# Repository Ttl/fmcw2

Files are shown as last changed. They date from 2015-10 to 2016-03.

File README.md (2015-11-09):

FMCW radar hardware, firmware and processing software.

Folders:

hardware: KiCad hardware design files.

- fmcw2: RF board.
- fmcw2_mcu: Digital board.

firmware: 
- Firmware for LPC4320 microcontroller. Based on [HackRF](https://github.com/mossmann/hackrf) firmware.

host: 
- Host programs for recording data, programming firmware. Also from HackRF with small modifications.

processing:
- fir: Resamples, filters and repackages samples for other programs.
- filter.py: Output FIR filter coefficients for fir C program.
- analysis.py: Various analyses about the recorded data.
- sar_bicycle.py: Pre-processing of raw data.
- sar_process.py: Focus raw data to SAR image.
- sar_autofocus.py: Simple minimum entropy autofocusing of SAR image.

SAR focusing program is loosely based on Matlab program by Gregory L. Charvat
and it also includes some functions from [RITSAR](https://github.com/dm6718/RITSAR).

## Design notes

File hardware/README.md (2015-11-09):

PCB info:

OSH Park 4-layer.

Material: FR408

Relative permittivity: 3.66

Tangent delta: 0.0127

Stackup:

- 1 mil solder resist
- 1 oz copper (1.4 mil)
- 6.7 mil prepreg
- 0.5 oz copper (0.7 mil)
- 47 mil core
- 0.5 oz copper (0.7 mil)
- 6.7 mil prepreg
- 1 oz copper (1.4 mil)
- 1 mil solder resist

More information: http://support.oshpark.com/support/solutions/articles/122263-4-layer-board-stackup-and-specifications

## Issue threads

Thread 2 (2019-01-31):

Bill of Materials?

zack-emmert, 2019-01-31:
I'm interested in re-creating this project, but I can't seem to find a list of all electronic components soldered to the PCBs. This information would be very helpful.

Ttl, 2019-02-01:
You can export a BOM from KiCad.

I strongly recommend building the next version of this radar in https://github.com/Ttl/fmcw3 instead of this one.

Closed 2019-02-01.

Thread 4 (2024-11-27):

can not find symbol and footprint

RaderWu, 2024-11-27:
The symbol and footprint for those KICAD schamtic and layout are missing...

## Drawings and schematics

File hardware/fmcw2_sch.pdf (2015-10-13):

# 100p BSW

100n 10V

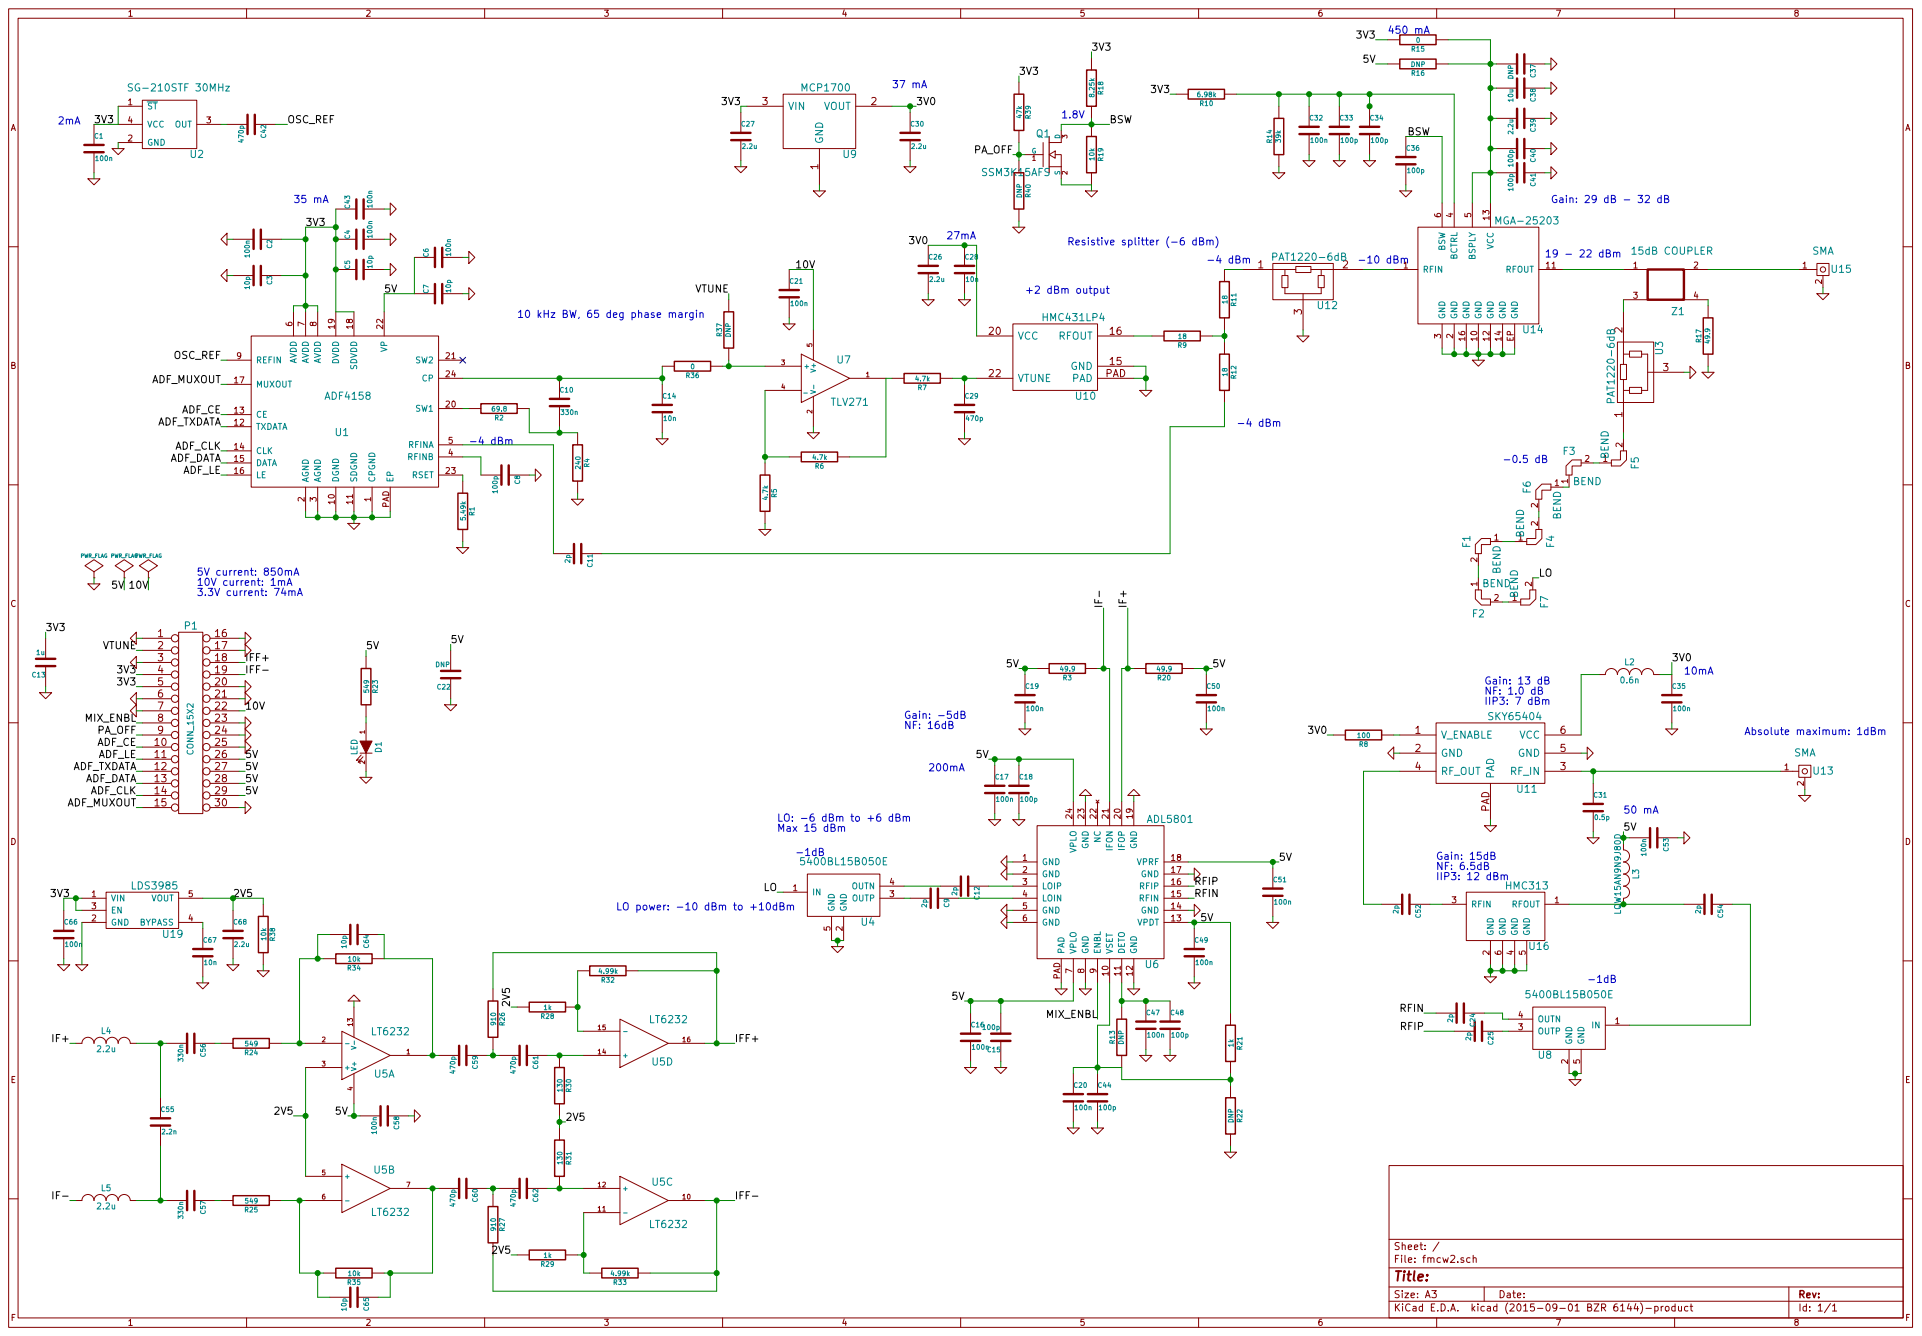
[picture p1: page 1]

6 GND 10 RFOUT 11 GND 12 VCC 13 GND 14 GND 16 GND EPU14 MGA-25203 C40 100p C39 2.2u 10u C38 DNP C37 C34

10 kHz BW, 65 deg phase margin

8 REFIN 9 DGND 10 SW1 20 SDGND 11 SW2 21 TXDATA 12 VP 22 CE 13 RSET 23 CLK 14 CP 24 DATA 15

9 VSET 10 IFOP 20 DETO 11 IFON 21 GND 12 NC 22 VPDT 13 GND 23 GND 14 VPLO 24 RFIN 15 RFIP 16 GND 17 VPRF 18 GND 19 PAD PADU6ADL5801 IF- IF+ RFIP RFIN

Id: 1/1 Title: File: fmcw2.sch Sheet: /

P0_1 G1 | P1_0 H1 | P1_3 J1 | P1_2 K1 | ADC0 A2 | VDDA B² VSSA C² USB_VDDA3V3 D2 | USB_DM E2 | USB_VSSA_REF F2
P1_4 J2 | P1_1 K2 | ADC3 A3 | ADC2 B3 | ALARM C3 | USB_VSSA_TERM D3 | USB_VBUS E3 | USB_RREF F3 | TDI G3 | TDO H3 | VSSIO J3 CLK0 K3 | WAKEUP0 A4 | TRSTN B4 | TMS C4 | VSSIO_40 D⁴ VDDREG_94 E⁴ VDDREG_59 F4 P1_7 G4

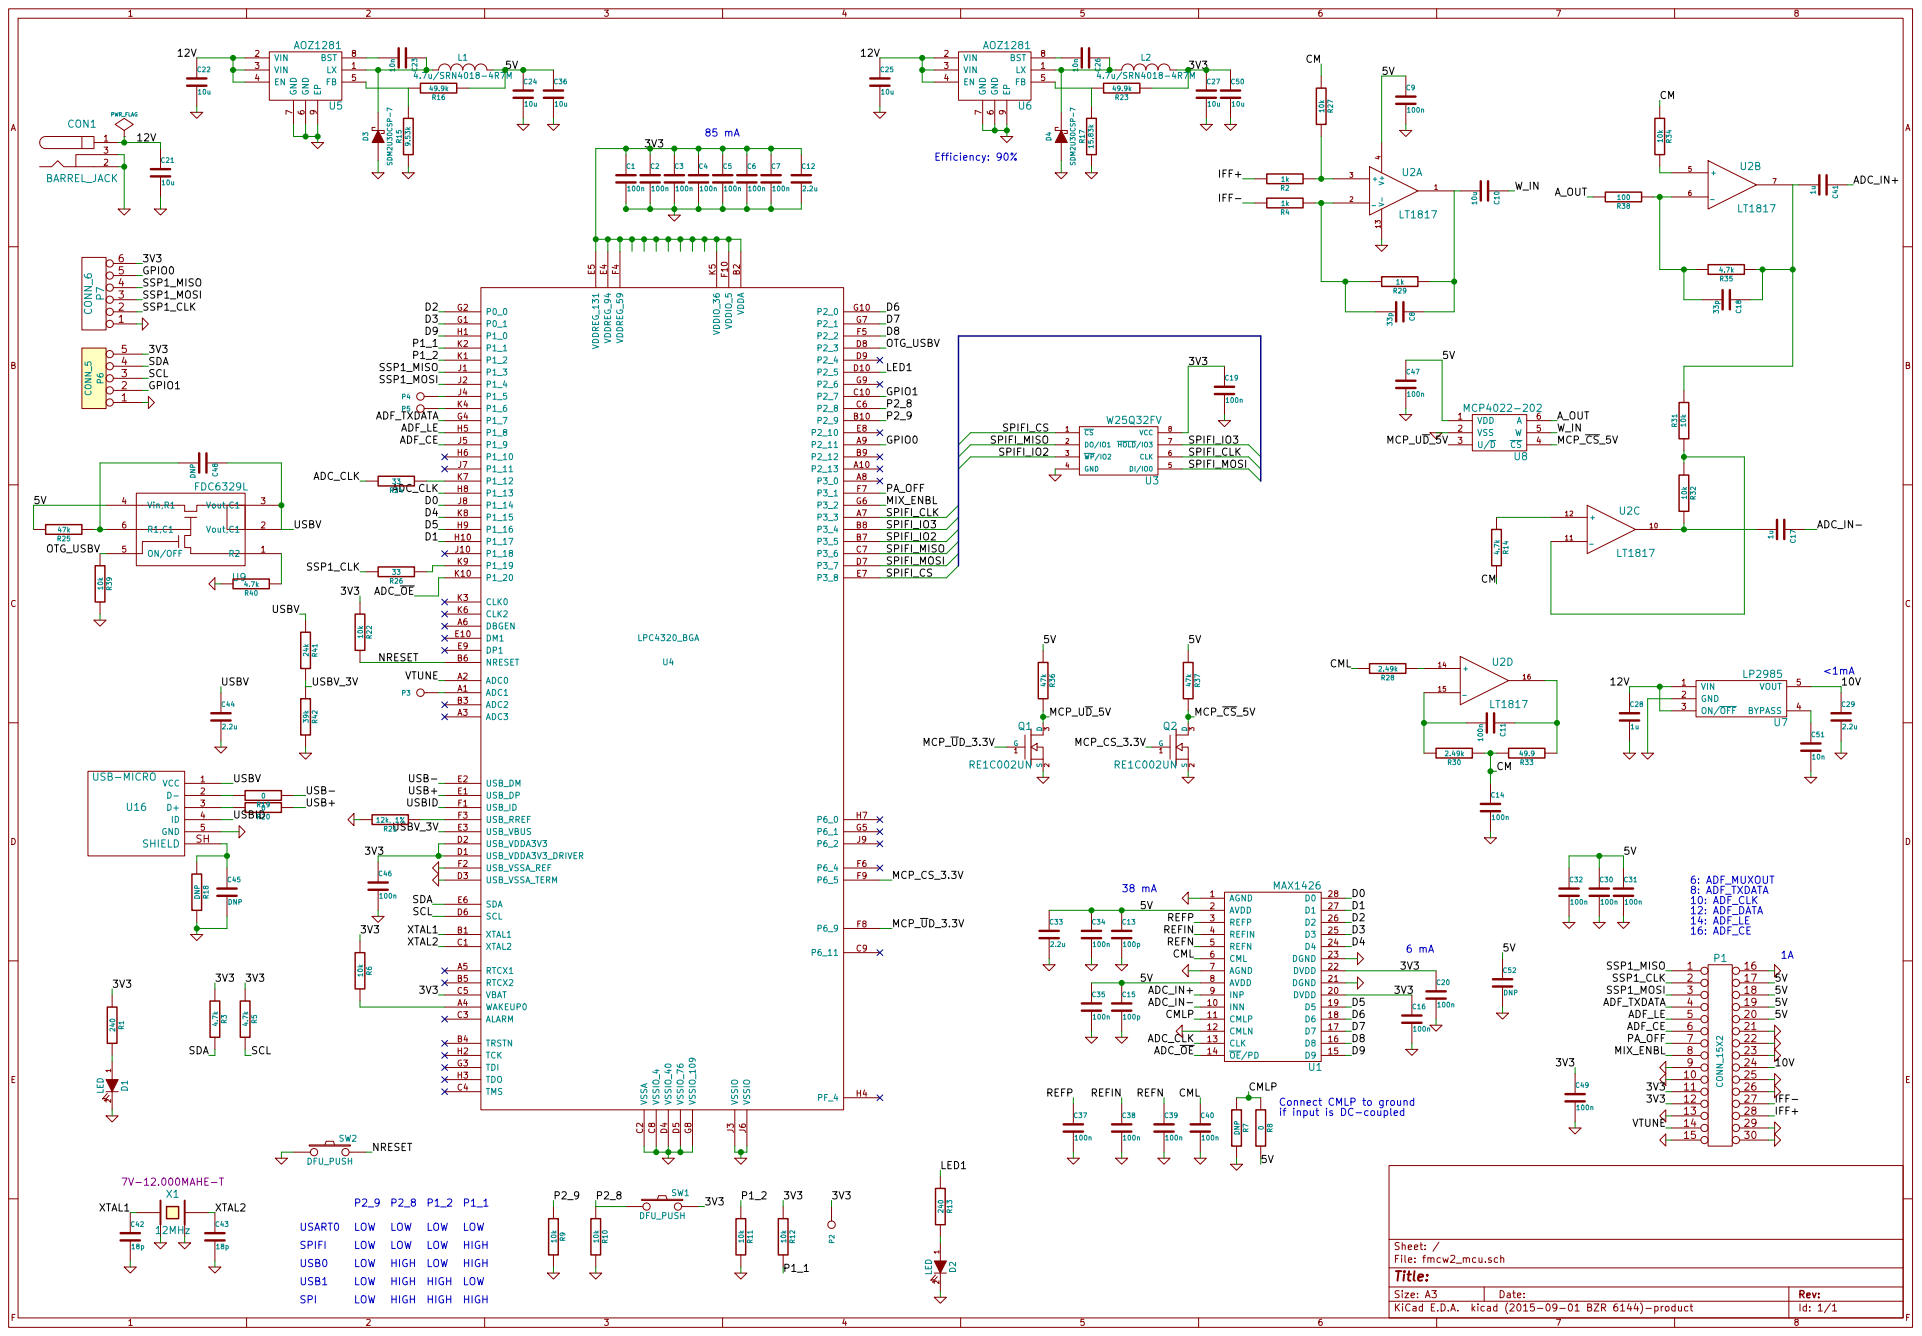
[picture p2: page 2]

VTUNE ²⁴k R⁴¹ 39k R⁴²

Connect CMLP to ground
if input is DC-coupled

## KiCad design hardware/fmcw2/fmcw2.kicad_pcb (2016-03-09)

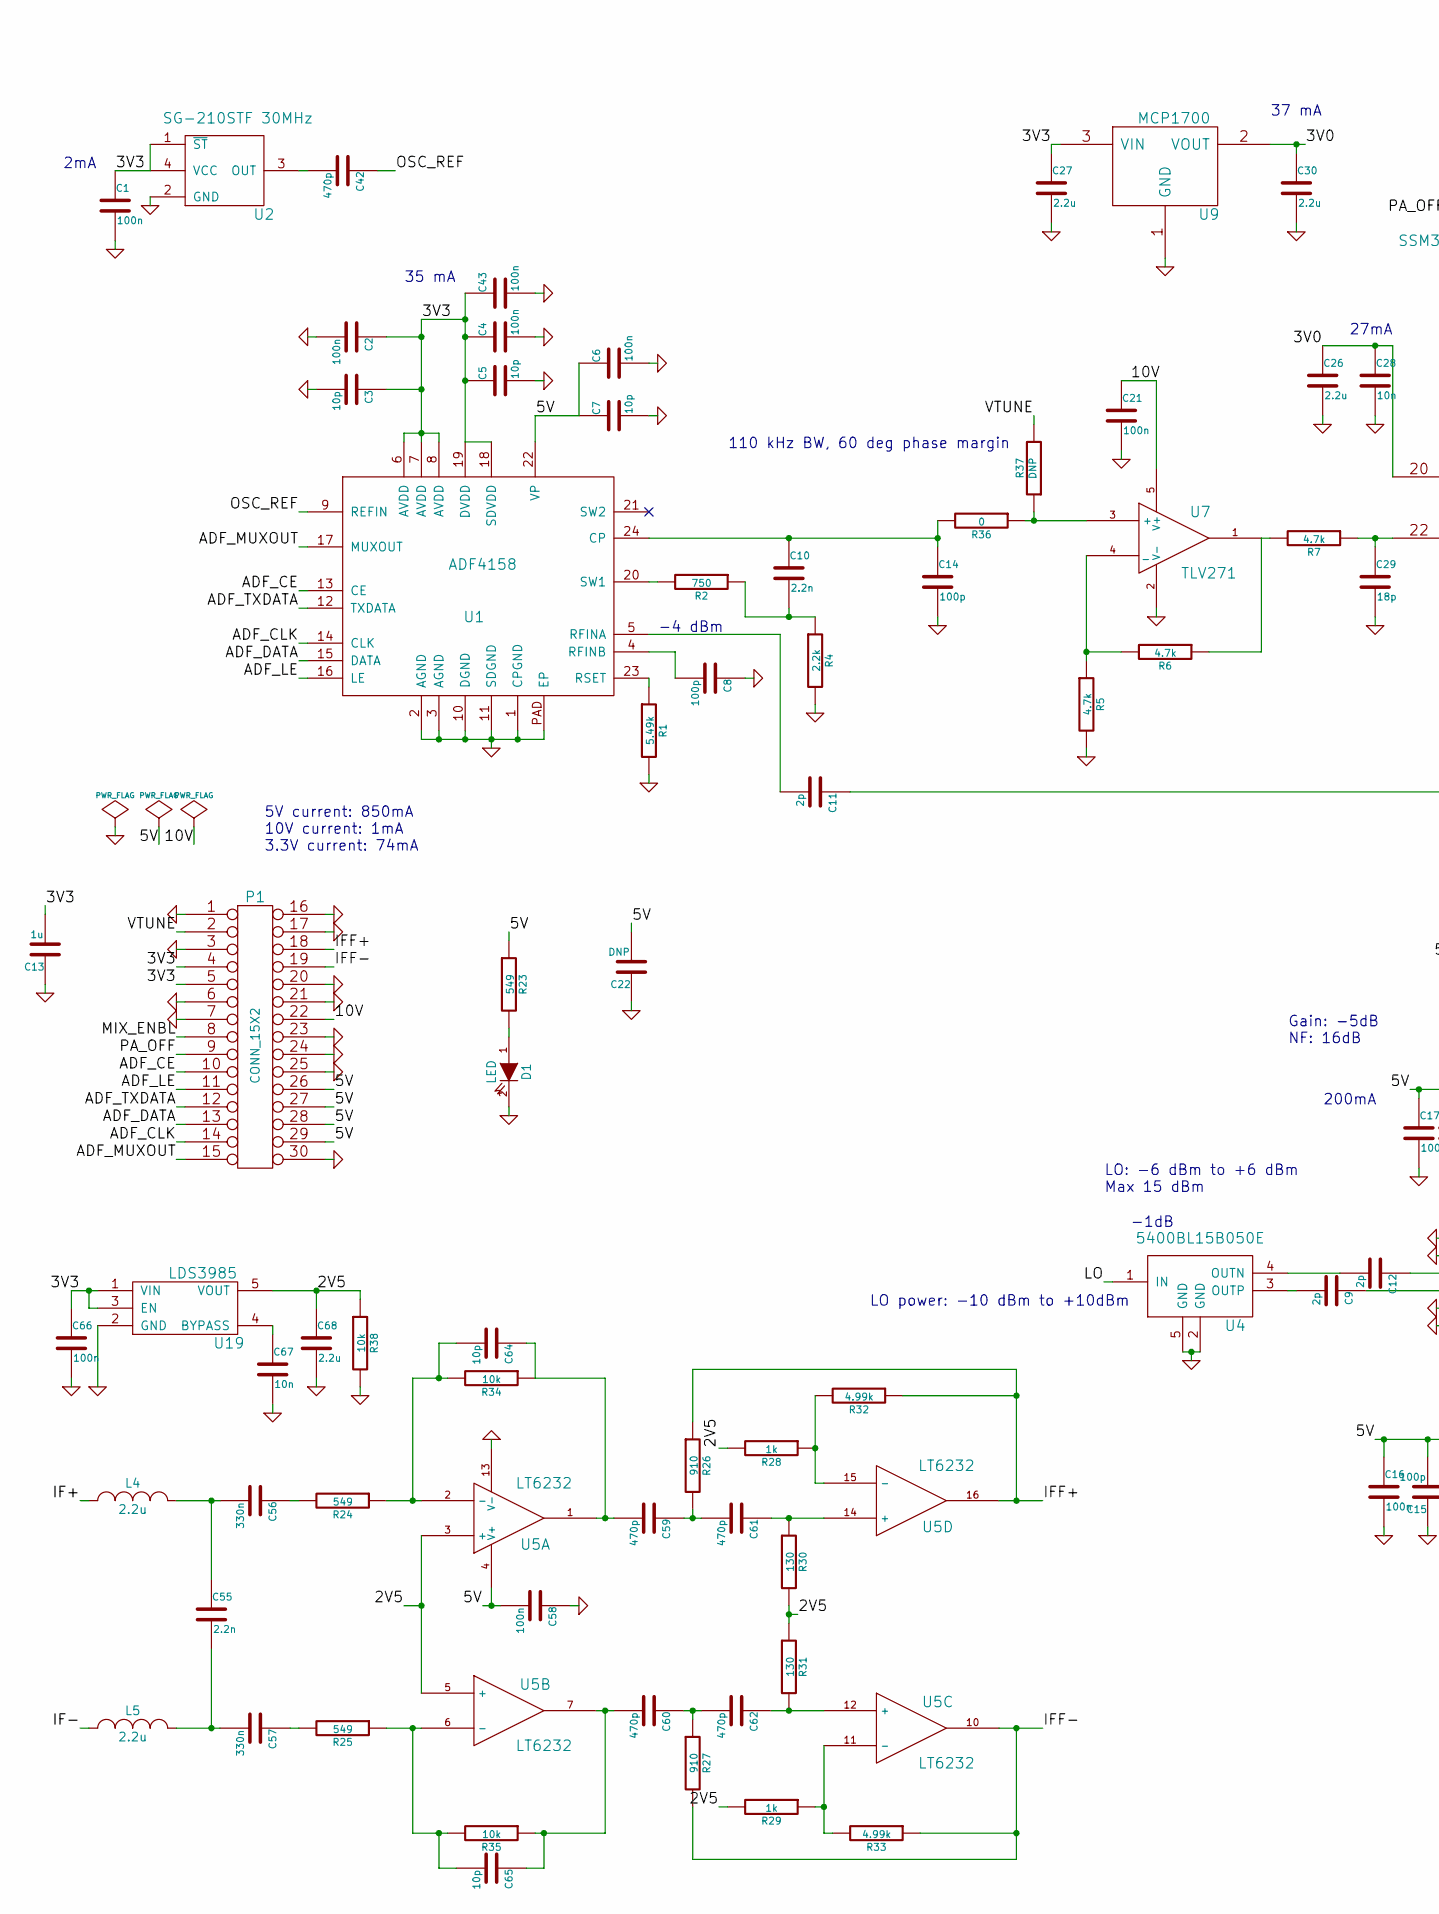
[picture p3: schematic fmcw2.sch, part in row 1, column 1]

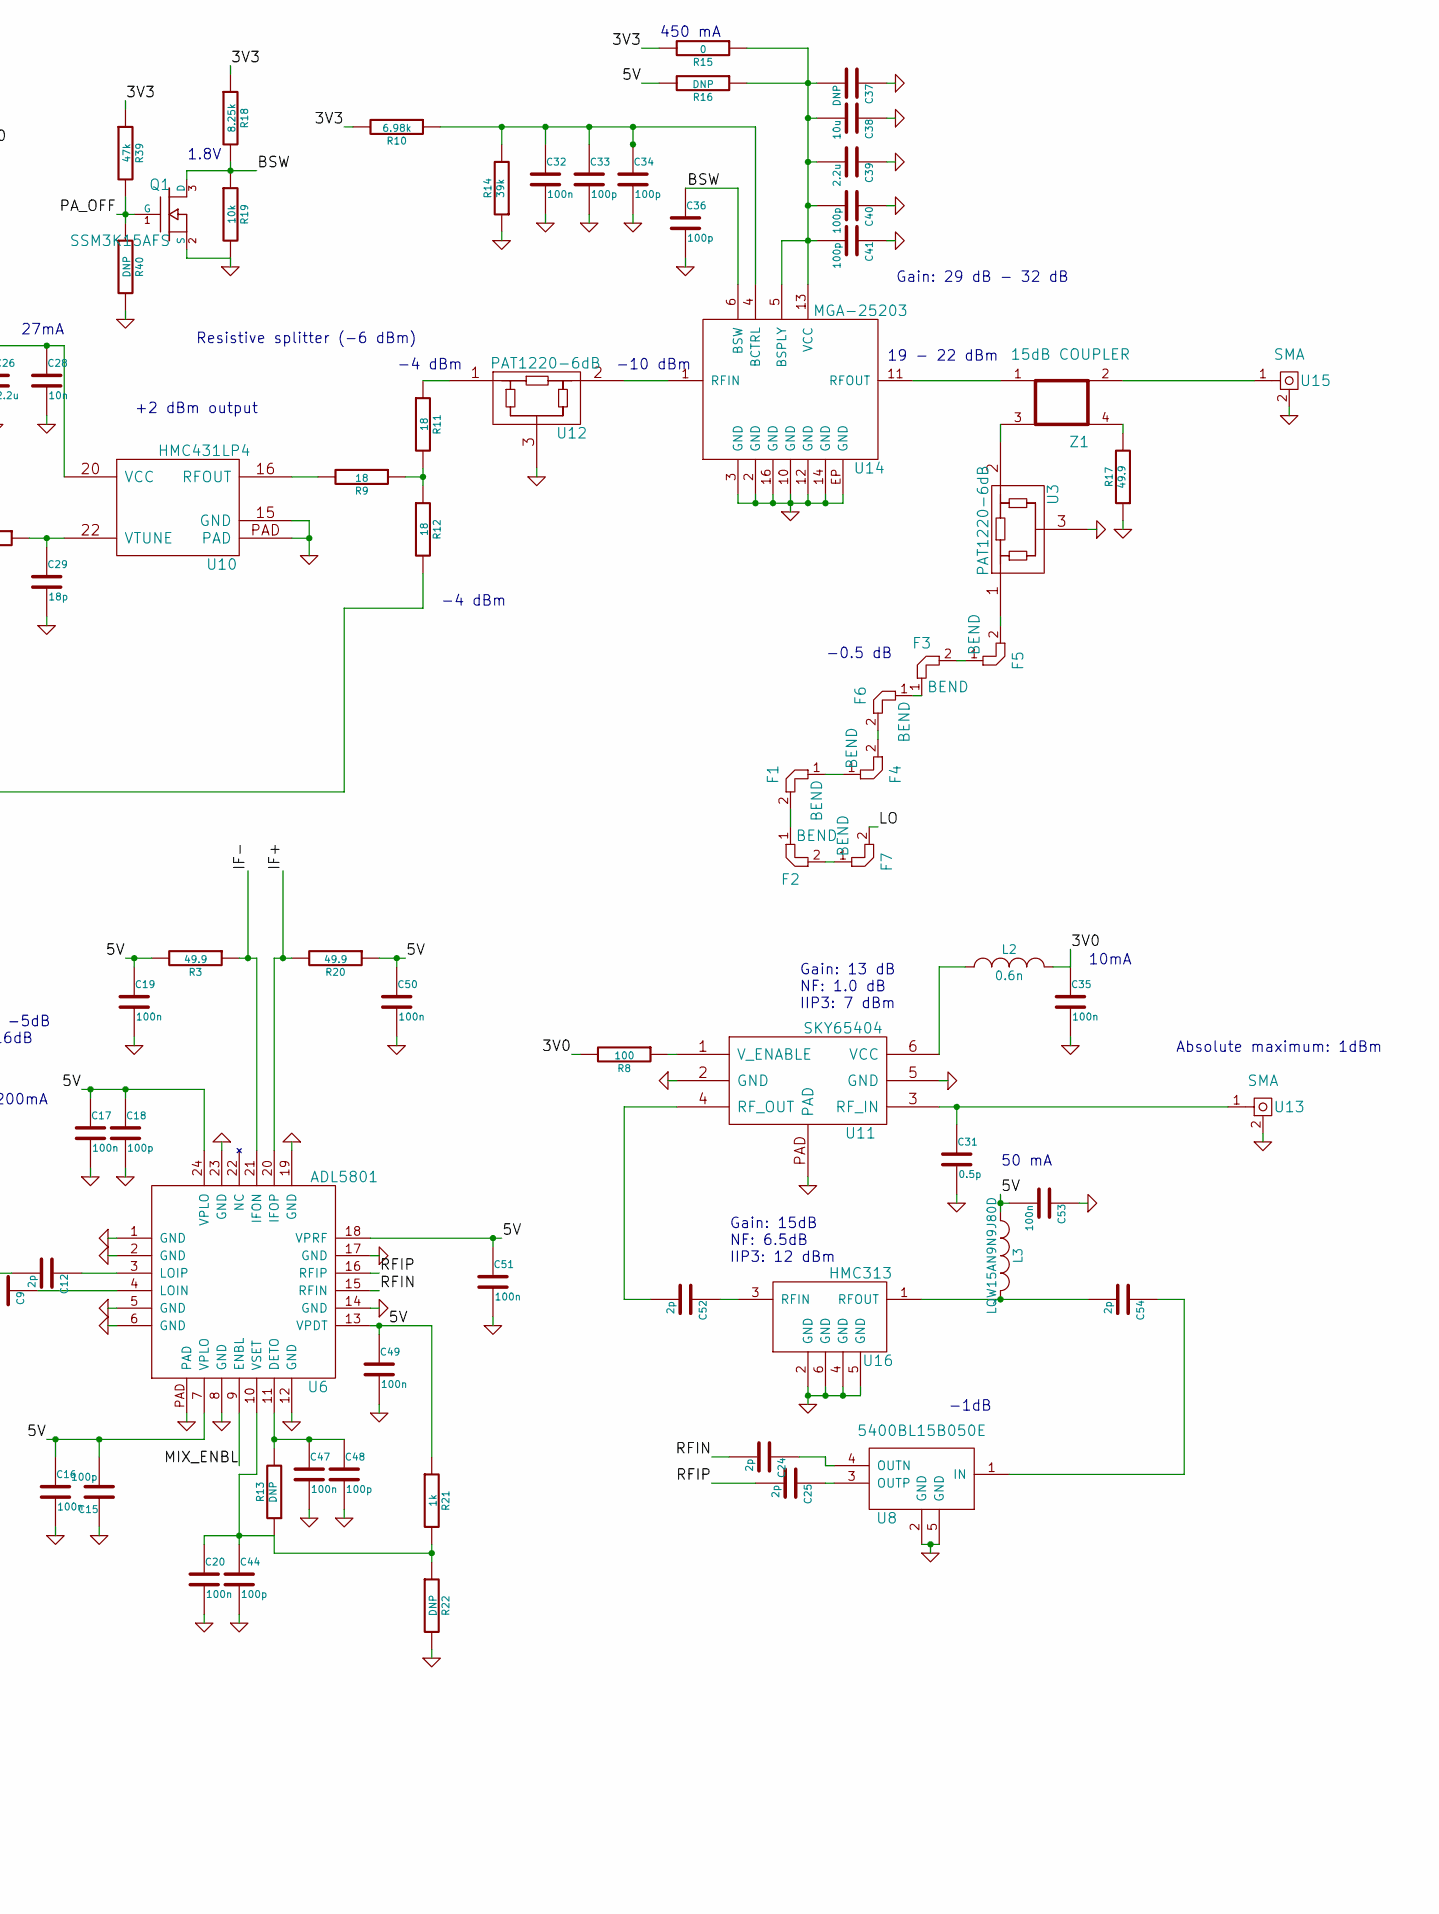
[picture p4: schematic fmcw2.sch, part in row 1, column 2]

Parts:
C1, C2, C4, C6, C16, C17, C19, C20, C21, C32, C35, C43, C47, C49, C50, C51, C53, C58, C66: 100n; C_0402b
C3, C5, C7, C64, C65: 10p; C_0402b
C8, C14, C15, C18, C33, C34, C36, C40, C41, C44, C48: 100p; C_0402b
C9, C11, C12, C24, C25, C52, C54: 2p; C_0402b
C10, C55: 2.2n; C_0402b
C13: 1u; C_0603b
C22: DNP; C_0805b
C26, C27, C30, C39, C68: 2.2u; C_0603b
C28, C67: 10n; C_0402b
C29: 18p; C_0402b
C31: 0.5p; C_0402b
C37: DNP; C_0603b
C38: 10u; C_0805b
C42, C59, C60, C61, C62: 470p; C_0402b
C56, C57: 330n; C_0603b
D1: LED; LED_0603
F1, F2, F7: BEND; uwmiter_0.34_0.17_90
F3, F4, F5, F6: BEND; uwmiter_0.34_0.17_45
L2: 0.6n; C_0402
L3: LQW15AN9N9J80D; C_0402
L4, L5: 2.2u; C_0402
P1: CONN_15X2; DF12B(5.0)-30DP-0.5V(86)
Q1: SSM3K15AFS; SOT-416
R1: 5.49k; R_0402b
R2: 750; R_0402b
R3, R17, R20: 49.9; R_0402b
R4: 2.2k; R_0402b
R5, R6, R7: 4.7k; R_0402b
R8: 100; R_0402b
R9, R11, R12: 18; R_0402b
R10: 6.98k; R_0402b
R13, R16, R22, R37, R40: DNP; R_0402b
R14: 39k; R_0402b
R15, R36: 0; R_0402b
R18: 8.25k; R_0402b
R19, R34, R35, R38: 10k; R_0402b
R21, R28, R29: 1k; R_0402b
R23, R24, R25: 549; R_0402b
R26, R27: 910; R_0402b
R30, R31: 130; R_0402b
R32, R33: 4.99k; R_0402b
R39: 47k; R_0402b
U1: ADF4158; VFQFN-24
U2: SG-210STF 30MHz; SG-210STF
U3, U12: PAT1220-6dB; PAT1220
U4, U8: 5400BL15B050E
U5: LT6232; SSOP-16_3.9x4.9mm_Pitch0.635mm
U6: ADL5801; VFQFN-24
U7: TLV271; SOT-23-5
U9: MCP1700; SOT-23
U10: HMC431LP4; VQFN-24
U11: SKY65404; XFDFN-6
U13, U15: SMA; CONSMA003.062
U14: MGA-25203
U16: HMC313; SOT-23-6
U19: LDS3985; SOT-23-5L
Z1: 15dB COUPLER; coupler

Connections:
/2V5: C68.1, R28.2, R29.2, R30.2, R31.1, R38.1, U5.3 (+), U5.5 (+), U19.5 (VOUT)
/3V0: C26.1, C28.1, C30.1, C35.1, L2.2, R8.2, U9.2 (VOUT), U10.20 (VCC)
/3V3: C1.1, C2.1, C3.1, C4.1, C5.1, C13.2, C27.1, C43.1, C66.1, P1.4, P1.5, R10.2, R15.2, R18.1, R39.1, U1.6 (AVDD), U1.7 (AVDD), U1.8 (AVDD), U1.18 (SDVDD), U1.19 (DVDD), U2.1 (~ST), U2.4 (VCC), U9.3 (VIN), U19.1 (VIN), U19.3 (EN)
/5V: C6.1, C7.1, C15.2, C16.1, C17.1, C18.1, C19.1, C22.2, C49.1, C50.1, C51.1, C53.2, C58.2, L3.1, P1.26, P1.27, P1.28, P1.29, R3.2, R16.2, R20.1, R21.1, R23.1, U1.22 (VP), U5.4 (V+), U6.7 (VPLO), U6.13 (VPDT), U6.18 (VPRF), U6.24 (VPLO)
/10V: C21.1, P1.22, U7.5 (V+)
/ADF_CE: P1.10, U1.13 (CE)
/ADF_CLK: P1.14, U1.14 (CLK)
/ADF_DATA: P1.13, U1.15 (DATA)
/ADF_LE: P1.11, U1.16 (LE)
/ADF_MUXOUT: P1.15, U1.17 (MUXOUT)
/ADF_TXDATA: P1.12, U1.12 (TXDATA)
/BSW: C36.1, Q1.3 (D), R18.2, R19.1, U14.6 (BSW)
/IF+: L4.1, R20.2, U6.20 (IFOP)
/IF-: L5.1, R3.1, U6.21 (IFON)
/IFF+: P1.18, R26.1, R32.1, U5.16
/IFF-: P1.19, R27.2, R33.1, U5.10
/LO: F7.2, U4.1 (IN)
/MIX_ENBL: P1.8, U6.9 (ENBL)
/OSC_REF: C42.1, U1.9 (REFIN)
/PA_OFF: P1.9, Q1.1 (G), R39.2, R40.1
/RFIN: C24.2, U6.15 (RFIN)
/RFIP: C25.2, U6.16 (RFIP)
/VTUNE: P1.2, R37.2
GND: C1.2, C2.2, C3.2, C4.2, C5.2, C6.2, C7.2, C8.1, C13.1, C14.2, C15.1, C16.2, C17.2, C18.2, C19.2, C20.2, C21.2, C22.1, C26.2, C27.2, C28.2, C29.2, C30.2, C31.2, C32.2, C33.2, C34.2, C35.2, C36.2, C37.1, C38.1, C39.1, C40.1, C41.1, C43.2, C44.2, C47.2, C48.2, C49.2, C50.2, C51.2, C53.1, C58.1, C66.2, C67.2, C68.2, D1.2 (K), P1.1, P1.3, P1.6, P1.7, P1.16, P1.17, P1.20, P1.21, P1.23, P1.24, P1.25, P1.30, Q1.2 (S), R1.2, R4.2, R5.2, R14.1, R17.1, R19.2, R22.2, R38.2, R40.2, U1.1 (CPGND), U1.2 (AGND), U1.3 (AGND), U1.10 (DGND), U1.11 (SDGND), U1.PAD (EP), U2.2 (GND), U3.3, U4.2 (GND), U4.5 (GND), U5.13 (V-), U6.1 (GND), U6.2 (GND), U6.5 (GND), U6.6 (GND), U6.8 (GND), U6.12 (GND), U6.14 (GND), U6.17 (GND), U6.19 (GND), U6.23 (GND), U6.PAD, U7.2 (V-), U8.2 (GND), U8.5 (GND), U9.1 (GND), U10.15 (GND), U10.PAD, U11.2 (GND), U11.5 (GND), U11.PAD, U12.3, U13.2, U14.2 (GND), U14.3 (GND), U14.10 (GND), U14.12 (GND), U14.14 (GND), U14.16 (GND), U14.EP (GND), U15.2, U16.2 (GND), U16.4 (GND), U16.5 (GND), U16.6 (GND), U19.2 (GND)
unnamed: C8.2, U1.4 (RFINB)
unnamed: C9.1, U6.4 (LOIN)
unnamed: C9.2, U4.3 (OUTP)
unnamed: C10.1, C14.1, R36.2, U1.24 (CP)
unnamed: C10.2, R2.1, R4.1
unnamed: C11.1, R12.2
unnamed: C11.2, U1.5 (RFINA)
unnamed: C12.1, U6.3 (LOIP)
unnamed: C12.2, U4.4 (OUTN)
unnamed: C20.1, C44.1, R13.1, R21.2, R22.1, U6.10 (VSET)
unnamed: C24.1, U8.4 (OUTN)
unnamed: C25.1, U8.3 (OUTP)
unnamed: C29.1, R7.1, U10.22 (VTUNE)
unnamed: C31.1, U11.3 (RF_IN), U13.1
unnamed: C32.1, C33.1, C34.1, R10.1, R14.2, U14.4 (BCTRL)
unnamed: C37.2, C38.2, C39.2, C40.2, C41.2, R15.1, R16.1, U14.5 (BSPLY), U14.13 (VCC)
unnamed: C42.2, U2.3 (OUT)
unnamed: C47.1, C48.1, R13.2, U6.11 (DETO)
unnamed: C52.1, U16.3 (RFIN)
unnamed: C52.2, U11.4 (RF_OUT)
unnamed: C54.1, U8.1 (IN)
unnamed: C54.2, L3.2, U16.1 (RFOUT)
unnamed: C55.1, C56.2, L4.2
unnamed: C55.2, C57.2, L5.2
unnamed: C56.1, R24.2
unnamed: C57.1, R25.2
unnamed: C59.1, C61.2, R26.2
unnamed: C59.2, C64.1, R34.1, U5.1
unnamed: C60.1, C62.2, R27.1
unnamed: C60.2, C65.1, R35.1, U5.7
unnamed: C61.1, R30.1, U5.14 (+)
unnamed: C62.1, R31.2, U5.12 (+)
unnamed: C64.2, R24.1, R34.2, U5.2 (-)
unnamed: C65.2, R25.1, R35.2, U5.6 (-)
unnamed: C67.1, U19.4 (BYPASS)
unnamed: D1.1 (A), R23.2
unnamed: F1.1, F4.1
unnamed: F1.2, F2.1
unnamed: F2.2, F7.1
unnamed: F3.1, F6.1
unnamed: F3.2, F5.1
unnamed: F4.2, F6.2
unnamed: F5.2, U3.1
unnamed: L2.1, U11.6 (VCC)
unnamed: R1.1, U1.23 (RSET)
unnamed: R2.2, U1.20 (SW1)
unnamed: R5.1, R6.2, U7.4 (_)
unnamed: R6.1, R7.2, U7.1
unnamed: R8.1, U11.1 (V_ENABLE)
unnamed: R9.2, U10.16 (RFOUT)
unnamed: R11.1, U12.1
unnamed: R9.1, R11.2, R12.1
unnamed: R17.2, Z1.4
unnamed: R28.1, R32.2, U5.15 (-)
unnamed: R29.1, R33.2, U5.11 (-)
unnamed: R36.1, R37.1, U7.3 (+)
unnamed: U3.2, Z1.3
unnamed: U12.2, U14.1 (RFIN)
unnamed: U14.11 (RFOUT), Z1.1
unnamed: U15.1, Z1.2

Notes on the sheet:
Resistive splitter (-6 dBm)
+2 dBm output
-4 dBm
27mA
-10 dBm
Gain: 29 dB - 32 dB
19 - 22 dBm
110 kHz BW, 60 deg phase margin
2mA
LO: -6 dBm to +6 dBm Max 15 dBm
35 mA
450 mA
10mA
37 mA
-1dB
1.8V
Gain: 13 dB NF: 1.0 dB IIP3: 7 dBm
Gain: -5dB NF: 16dB
200mA
LO power: -10 dBm to +10dBm
Gain: 15dB NF: 6.5dB IIP3: 12 dBm
50 mA
Absolute maximum: 1dBm
5V current: 850mA 10V current: 1mA 3.3V current: 74mA
-0.5 dB

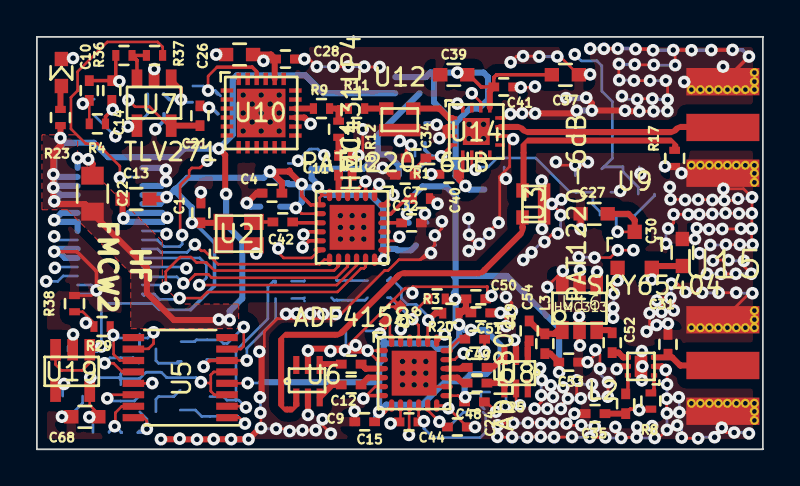
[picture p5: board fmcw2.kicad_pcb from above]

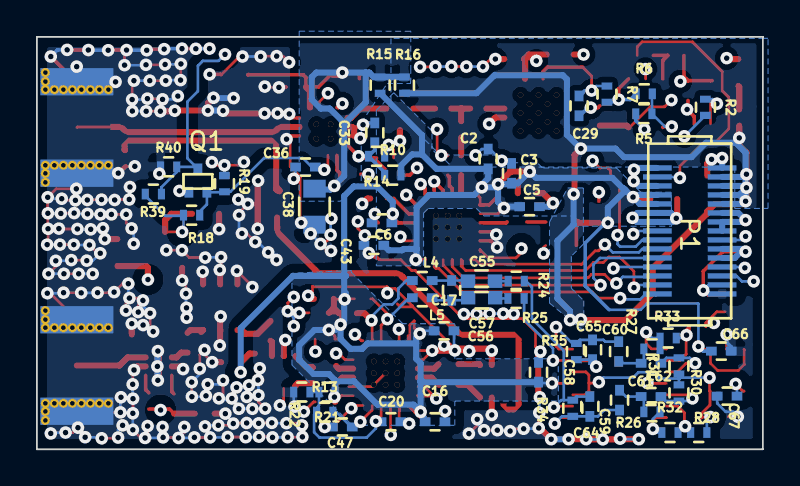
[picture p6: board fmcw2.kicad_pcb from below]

Board: 4 copper layers, 40.3 x 22.9 mm, 136 parts (55 on the bottom side), 84 nets.

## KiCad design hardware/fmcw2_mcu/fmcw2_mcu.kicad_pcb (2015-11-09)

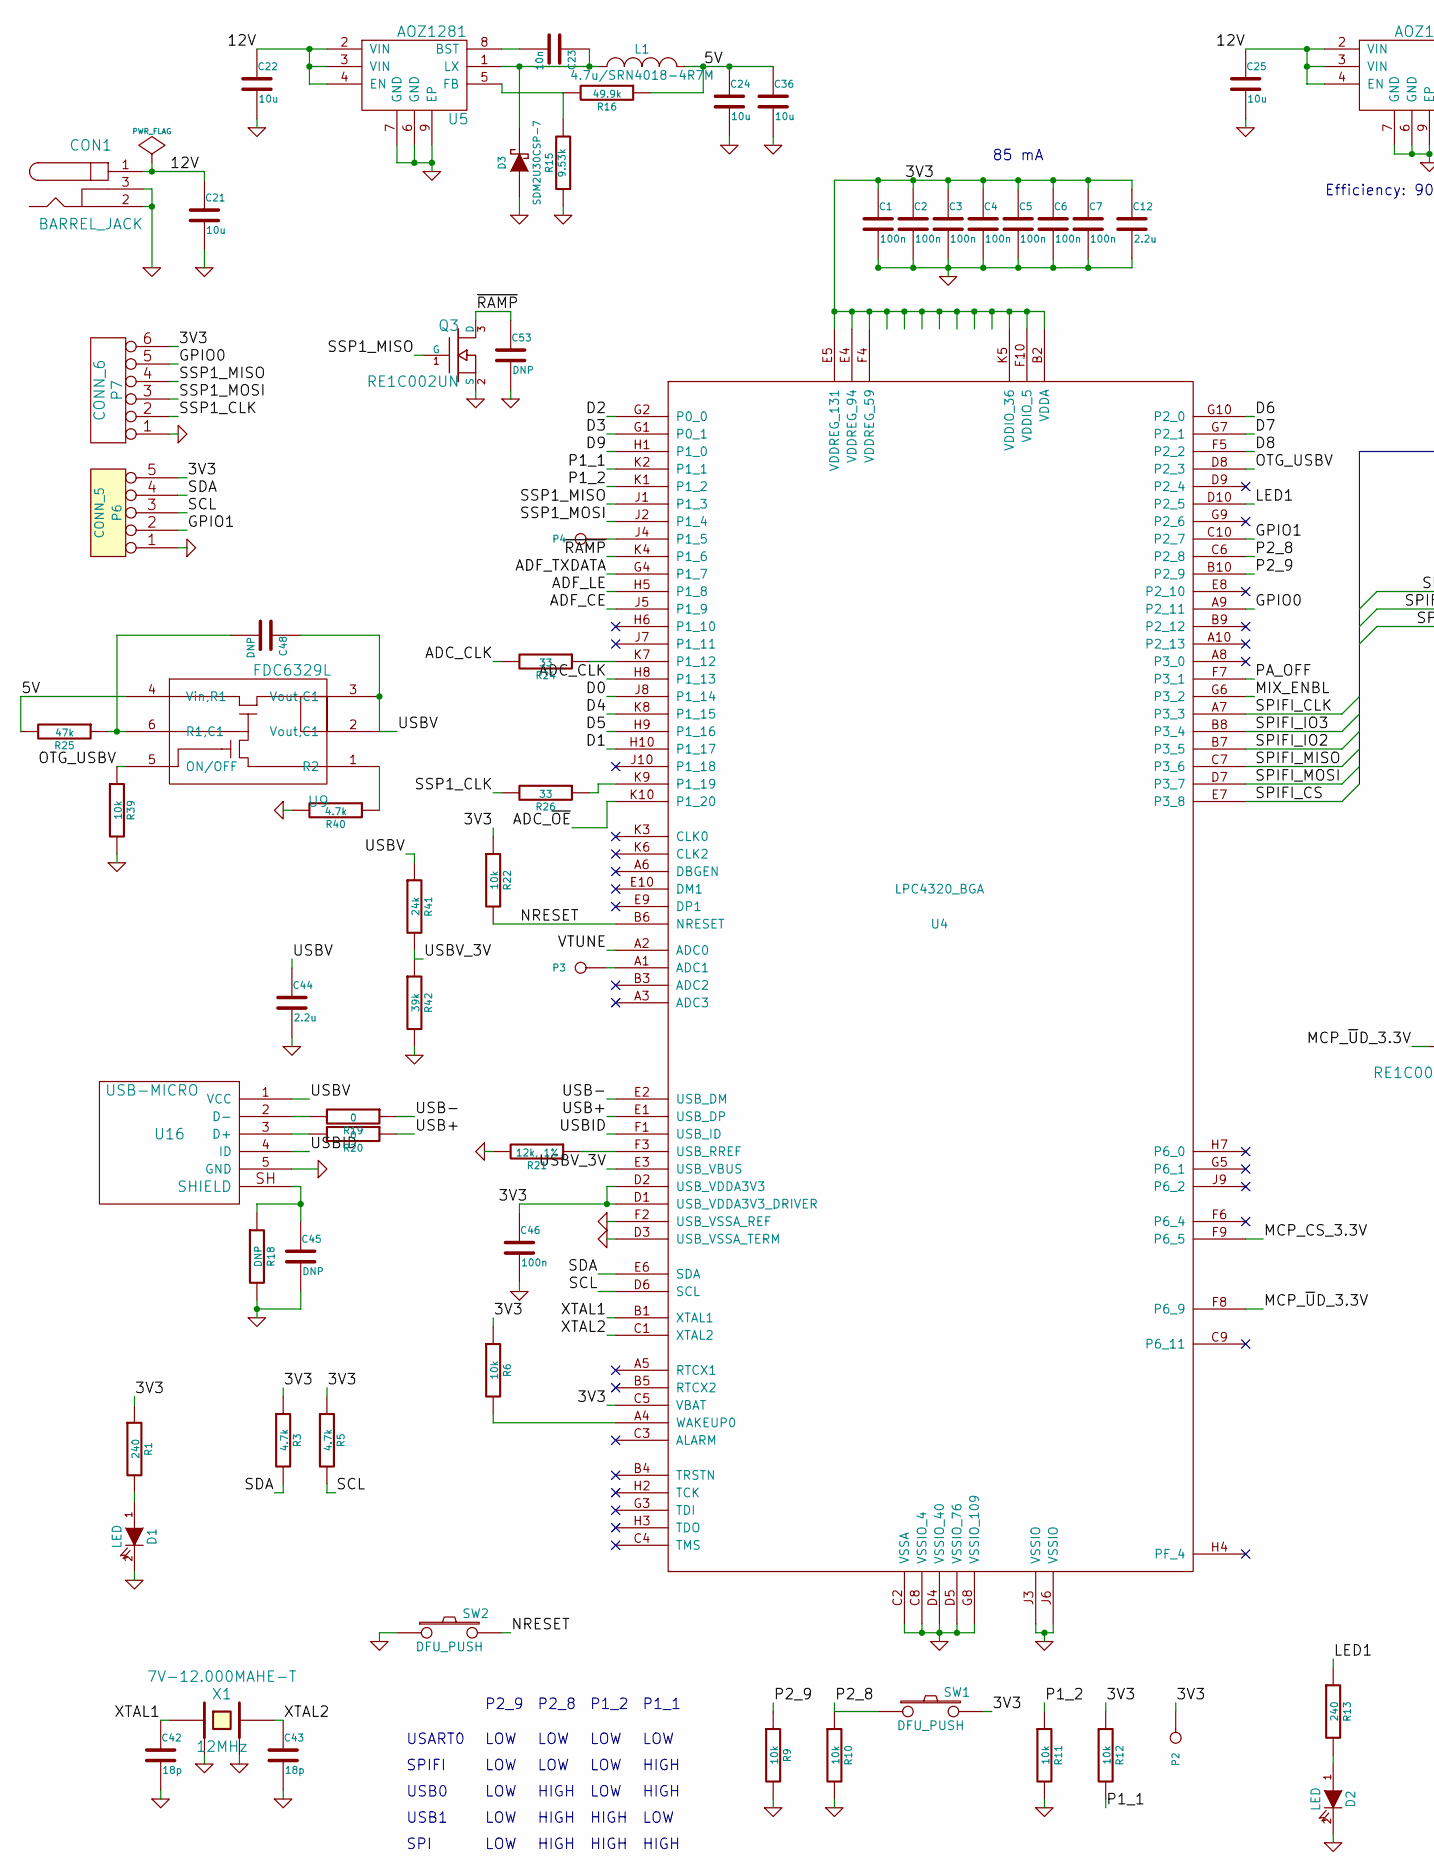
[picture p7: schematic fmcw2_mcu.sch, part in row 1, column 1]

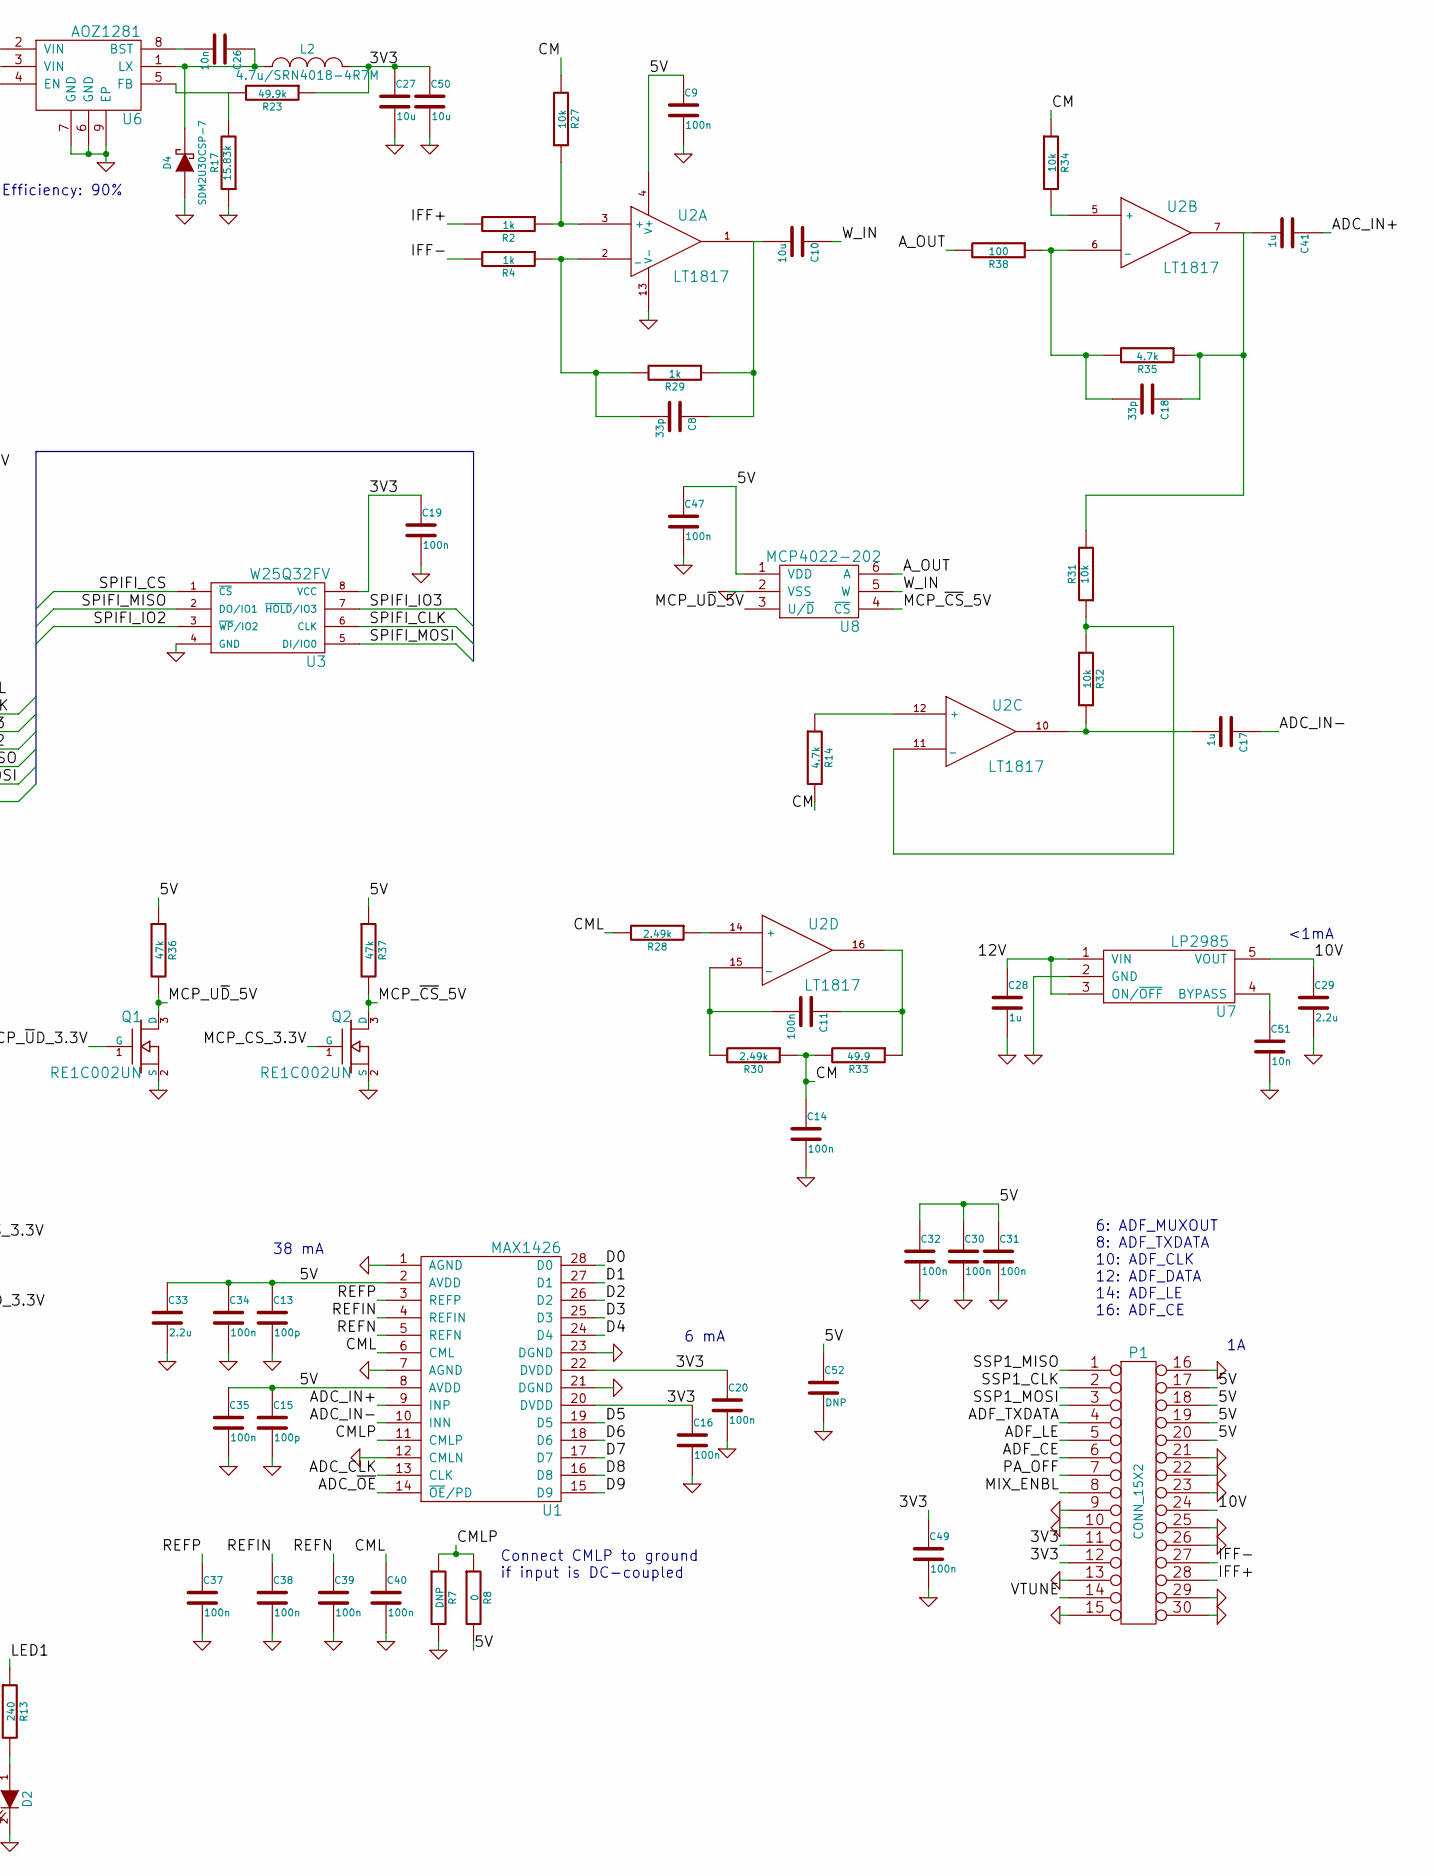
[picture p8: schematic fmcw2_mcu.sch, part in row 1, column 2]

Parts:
C1, C2, C3, C4, C5, C6, C7, C9, C11, C14, C16, C19, C20, C30, C31, C32, C34, C35, C37, C38, C39, C40, C46, C47, C49: 100n; C_0402b
C8, C18: 33p; C_0402b
C10, C21, C22, C24, C25, C27, C36, C50: 10u; C_0805b
C12, C29, C33, C44: 2.2u; C_0603b
C13, C15: 100p; C_0402b
C17, C28, C41: 1u; C_0603b
C23, C26, C51: 10n; C_0402b
C42, C43: 18p; C_0402b
C45, C48, C53: DNP; C_0402b
C52: DNP; C_0603b
CON1: BARREL_JACK; EJ508A
D1, D2: LED; LED_0603
D3, D4: SDM2U30CSP-7; XDFN-2
L1, L2: 4.7u/SRN4018-4R7M; SRN4018
P1: CONN_15X2; DF12A-30DS-0.5V(81)
P2, P3, P4: CONN_1; TP_1.00
P6: CONN_5; Pin_Header_Straight_1x05
P7: CONN_6; Pin_Header_Straight_1x06
Q1, Q2, Q3: RE1C002UN; SOT-416
R1, R13: 240; R_0402b
R2, R4, R29: 1k; R_0402b
R3, R5, R14, R35, R40: 4.7k; R_0402b
R6, R9, R10, R11, R12, R22, R27, R31, R32, R34, R39: 10k; R_0402b
R7, R18: DNP; R_0402b
R8, R19, R20: 0; R_0402b
R15: 9.53k; R_0402b
R16, R23: 49.9k; R_0402b
R17: 15.83k; R_0402b
R21: 12k, 1%; R_0402b
R24, R26: 33; R_0402b
R25, R36, R37: 47k; R_0402b
R28, R30: 2.49k; R_0402b
R33: 49.9; R_0402b
R38: 100; R_0402b
R41: 24k; R_0402b
R42: 39k; R_0402b
SW1, SW2: DFU_PUSH; EVP-AWBA2A
U1: MAX1426; SSOP-28_5.3x10.2mm_Pitch0.65mm
U2: LT1817; SSOP-16_3.9x4.9mm_Pitch0.635mm
U3: W25Q32FV; SOIJ-8_5.3x5.3mm_Pitch1.27mm
U4: LPC4320_BGA; TFBGA-100
U5, U6: AOZ1281; WFDFN-8
U7: LP2985; SOT-23-5
U8: MCP4022-202; SOT-23-6
U9: FDC6329L; SSOT-6
U16: USB-MICRO; USB_MICRO
X1: 12MHz; XTAL_3.2x2.5

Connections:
/3V3: C1.1, C2.1, C3.1, C4.1, C5.1, C6.1, C7.1, C12.1, C16.1, C19.1, C20.1, C27.1, C46.1, C49.1, C50.1, L2.2, P1.11, P1.12, P2.1, P6.5, P7.6, R1.1, R3.1, R5.1, R6.1, R12.1, R22.1, R23.1, SW1.2, U1.20 (DVDD), U1.22 (DVDD), U3.8 (VCC), U4.B2 (VDDA), U4.C5 (VBAT), U4.D1 (USB_VDDA3V3_DRIVER), U4.D2 (USB_VDDA3V3), U4.E4 (VDDREG_94), U4.E5 (VDDREG_131), U4.F4 (VDDREG_59), U4.F10 (VDDIO_5), U4.K5 (VDDIO_36)
/5V: C9.1, C13.1, C15.1, C24.1, C30.1, C31.1, C32.1, C33.1, C34.1, C35.1, C36.1, C47.1, C52.1, L1.2, P1.17, P1.18, P1.19, P1.20, R8.2, R16.1, R25.2, R36.1, R37.1, U1.2 (AVDD), U1.8 (AVDD), U2.4 (V+), U8.1 (VDD), U9.4 (Vin,R1)
/10V: C29.1, P1.24, U7.5 (VOUT)
/12V: C21.1, C22.1, C25.1, C28.1, CON1.1, U5.2 (VIN), U5.3 (VIN), U5.4 (EN), U6.2 (VIN), U6.3 (VIN), U6.4 (EN), U7.1 (VIN), U7.3 (ON/~OFF~)
/ADC_CLK: R24.2, U1.13 (CLK), U4.H8 (P1_13)
/ADC_IN+: C41.1, U1.9 (INP)
/ADC_IN-: C17.1, U1.10 (INN)
/ADC_~OE~: U1.14 (~OE~/PD), U4.K10 (P1_20)
/ADF_CE: P1.6, U4.J5 (P1_9)
/ADF_LE: P1.5, U4.H5 (P1_8)
/ADF_TXDATA: P1.4, U4.G4 (P1_7)
/A_OUT: R38.2, U8.6 (A)
/CM: C14.1, R14.2, R27.2, R30.1, R33.2, R34.1
/CML: C40.1, R28.2, U1.6 (CML)
/CMLP: R7.1, R8.1, U1.11 (CMLP)
/D0: U1.28 (D0), U4.J8 (P1_14)
/D1: U1.27 (D1), U4.H10 (P1_17)
/D2: U1.26 (D2), U4.G2 (P0_0)
/D3: U1.25 (D3), U4.G1 (P0_1)
/D4: U1.24 (D4), U4.K8 (P1_15)
/D5: U1.19 (D5), U4.H9 (P1_16)
/D6: U1.18 (D6), U4.G10 (P2_0)
/D7: U1.17 (D7), U4.G7 (P2_1)
/D8: U1.16 (D8), U4.F5 (P2_2)
/D9: U1.15 (D9), U4.H1 (P1_0)
/GPIO0: P7.5, U4.A9 (P2_11)
/GPIO1: P6.2, U4.C10 (P2_7)
/IFF+: P1.28, R2.2
/IFF-: P1.27, R4.2
/LED1: R13.1, U4.D10 (P2_5)
/MCP_CS_3.3V: Q2.1 (G), U4.F9 (P6_5)
/MCP_U~D~_5V: Q1.3 (D), R36.2, U8.3 (U/~D~)
/MCP_~CS~_5V: Q2.3 (D), R37.2, U8.4 (~CS~)
/MCP_~U~D_3.3V: Q1.1 (G), U4.F8 (P6_9)
/MIX_ENBL: P1.8, U4.G6 (P3_2)
/NRESET: R22.2, SW2.2, U4.B6 (NRESET)
/OTG_USBV: R39.1, U4.D8 (P2_3), U9.5 (ON/OFF)
/P1_1: R12.2, U4.K2 (P1_1)
/P1_2: R11.1, U4.K1 (P1_2)
/P2_8: R10.1, SW1.1, U4.C6 (P2_8)
/P2_9: R9.1, U4.B10 (P2_9)
/PA_OFF: P1.7, U4.F7 (P3_1)
/REFIN: C38.1, U1.4 (REFIN)
/REFN: C39.1, U1.5 (REFN)
/REFP: C37.1, U1.3 (REFP)
/SCL: P6.3, R5.2, U4.D6 (SCL)
/SDA: P6.4, R3.2, U4.E6 (SDA)
/SPIFI_CLK: U3.6 (CLK), U4.A7 (P3_3)
/SPIFI_CS: U3.1 (~CS), U4.E7 (P3_8)
/SPIFI_IO2: U3.3 (~WP~/IO2), U4.B7 (P3_5)
/SPIFI_IO3: U3.7 (~HOLD~/IO3), U4.B8 (P3_4)
/SPIFI_MISO: U3.2 (DO/IO1), U4.C7 (P3_6)
/SPIFI_MOSI: U3.5 (DI/IO0), U4.D7 (P3_7)
/SSP1_CLK: P1.2, P7.2, R26.2
/SSP1_MISO: P1.1, P7.4, Q3.1 (G), U4.J1 (P1_3)
/SSP1_MOSI: P1.3, P7.3, U4.J2 (P1_4)
/USB+: R20.1, U4.E1 (USB_DP)
/USB-: R19.1, U4.E2 (USB_DM)
/USBID: U4.F1 (USB_ID), U16.4 (ID)
/USBV: C44.1, C48.1, R41.1, U9.2 (Vout,C1), U9.3 (Vout,C1), U16.1 (VCC)
/USBV_3V: R41.2, R42.1, U4.E3 (USB_VBUS)
/VTUNE: P1.14, U4.A2 (ADC0)
/W_IN: C10.1, U8.5 (W)
/XTAL1: C42.1, U4.B1 (XTAL1), X1.1
/XTAL2: C43.1, U4.C1 (XTAL2), X1.3
/~RAMP: C53.1, Q3.3 (D), U4.K4 (P1_6)
GND: C1.2, C2.2, C3.2, C4.2, C5.2, C6.2, C7.2, C9.2, C12.2, C13.2, C14.2, C15.2, C16.2, C19.2, C20.2, C21.2, C22.2, C24.2, C25.2, C27.2, C28.2, C29.2, C30.2, C31.2, C32.2, C33.2, C34.2, C35.2, C36.2, C37.2, C38.2, C39.2, C40.2, C42.2, C43.2, C44.2, C45.2, C46.2, C47.2, C49.2, C50.2, C51.2, C52.2, C53.2, CON1.2, CON1.3, D1.2 (K), D2.2 (K), D3.1 (A), D4.1 (A), P1.9, P1.10, P1.13, P1.15, P1.16, P1.21, P1.22, P1.23, P1.25, P1.26, P1.29, P1.30, P6.1, P7.1, Q1.2 (S), Q2.2 (S), Q3.2 (S), R7.2, R9.2, R10.2, R11.2, R15.1, R17.1, R18.2, R21.2, R39.2, R40.2, R42.2, SW2.1, U1.1 (AGND), U1.7 (AGND), U1.12 (CMLN), U1.21 (DGND), U1.23 (DGND), U2.13 (V-), U3.4 (GND), U4.C2 (VSSA), U4.C8 (VSSIO_4), U4.D3 (USB_VSSA_TERM), U4.D4 (VSSIO_40), U4.D5 (VSSIO_76), U4.F2 (USB_VSSA_REF), U4.G8 (VSSIO_109), U4.J3 (VSSIO), U4.J6 (VSSIO), U5.6 (GND), U5.7 (GND), U5.9 (EP), U6.6 (GND), U6.7 (GND), U6.9 (EP), U7.2 (GND), U8.2 (VSS), U16.5 (GND), X1.2, X1.4
unnamed: C8.2, R4.1, R29.2, U2.2 (_)
unnamed: C8.1, C10.2, R29.1, U2.1
unnamed: C11.1, R33.1, U2.16
unnamed: C11.2, R30.2, U2.15 (_)
unnamed: C17.2, R32.2, U2.10
unnamed: C18.1, C41.2, R31.2, R35.1, U2.7
unnamed: C18.2, R35.2, R38.1, U2.6 (_)
unnamed: C23.1, D3.2 (K), L1.1, U5.1 (LX)
unnamed: C23.2, U5.8 (BST)
unnamed: C26.1, D4.2 (K), L2.1, U6.1 (LX)
unnamed: C26.2, U6.8 (BST)
unnamed: C45.1, R18.1, U16.SH (SHIELD)
unnamed: C48.2, R25.1, U9.6 (R1,C1)
unnamed: C51.1, U7.4 (BYPASS)
unnamed: D1.1 (A), R1.2
unnamed: D2.1 (A), R13.2
unnamed: P3.1, U4.A1 (ADC1)
unnamed: P4.1, U4.J4 (P1_5)
unnamed: R2.1, R27.1, U2.3 (+)
unnamed: R6.2, U4.A4 (WAKEUP0)
unnamed: R14.1, U2.12 (+)
unnamed: R15.2, R16.2, U5.5 (FB)
unnamed: R17.2, R23.2, U6.5 (FB)
unnamed: R19.2, U16.2 (D-)
unnamed: R20.2, U16.3 (D+)
unnamed: R21.1, U4.F3 (USB_RREF)
unnamed: R24.1, U4.K7 (P1_12)
unnamed: R26.1, U4.K9 (P1_19)
unnamed: R28.1, U2.14 (+)
unnamed: R31.1, R32.1, U2.11 (_)
unnamed: R34.2, U2.5 (+)
unnamed: R40.1, U9.1 (R2)

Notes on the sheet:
LOW
P2_9
P2_8
P1_2
P1_1
SPIFI
USART0
HIGH
USB0
USB1
SPI
6: ADF_MUXOUT 8: ADF_TXDATA 10: ADF_CLK 12: ADF_DATA 14: ADF_LE 16: ADF_CE
38 mA
6 mA
Efficiency: 90%
85 mA
<1mA
Connect CMLP to ground if input is DC-coupled

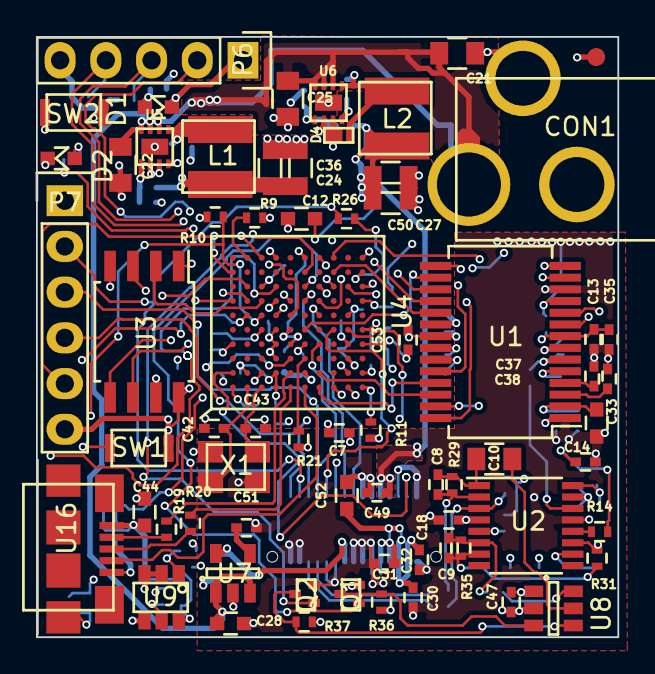
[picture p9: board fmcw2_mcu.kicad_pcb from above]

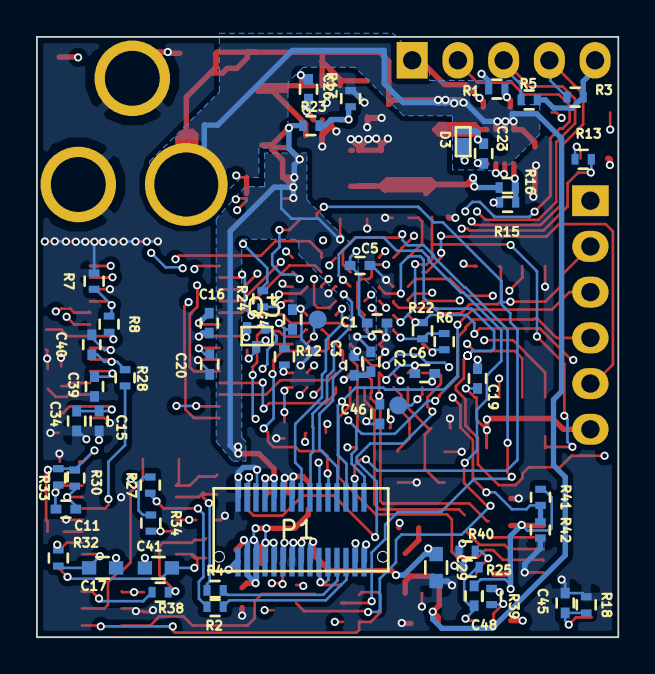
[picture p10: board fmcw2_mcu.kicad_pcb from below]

Board: 4 copper layers, 32.3 x 33.3 mm, 124 parts (56 on the bottom side), 99 nets.

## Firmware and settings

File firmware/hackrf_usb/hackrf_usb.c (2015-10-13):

/*
 * Copyright 2012 Jared Boone
 * Copyright 2013 Benjamin Vernoux
 *
 * This file is part of HackRF.
 *
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
 * You should have received a copy of the GNU General Public License
 * along with this program; see the file COPYING.  If not, write to
 * the Free Software Foundation, Inc., 51 Franklin Street,
 * Boston, MA 02110-1301, USA.
 */

#include <stddef.h>

#include <libopencm3/cm3/vector.h>

#include <libopencm3/lpc43xx/scu.h>
#include <libopencm3/lpc43xx/gpio.h>
#include <libopencm3/lpc43xx/m4/nvic.h>

#include <streaming.h>

#include "usb.h"
#include "usb_standard_request.h"

#include <rom_iap.h>
#include "usb_descriptor.h"

#include "usb_device.h"
#include "usb_endpoint.h"
#include "usb_api_board_info.h"
#include "usb_api_cpld.h"
#include "usb_api_register.h"
#include "usb_api_spiflash.h"

#include "usb_api_transceiver.h"
#include "rf_path.h"
#include "sgpio_isr.h"
#include "usb_bulk_buffer.h"
#include "sgpio.h"
#include "mcp4022.h"

static volatile transceiver_mode_t _transceiver_mode = TRANSCEIVER_MODE_OFF;

static unsigned int phase = 1;

void set_transceiver_mode(const transceiver_mode_t new_transceiver_mode) {
	baseband_streaming_disable();

	usb_endpoint_disable(&usb_endpoint_bulk_in);
	usb_endpoint_disable(&usb_endpoint_bulk_out);

	_transceiver_mode = new_transceiver_mode;

	if( _transceiver_mode == TRANSCEIVER_MODE_RX ) {
        usb_endpoint_init(&usb_endpoint_bulk_in);
        usb_bulk_buffer_offset = 0;
        phase = 1;
	} else if (_transceiver_mode == TRANSCEIVER_MODE_TX) {
		//usb_endpoint_init(&usb_endpoint_bulk_out);
	}

	if( _transceiver_mode != TRANSCEIVER_MODE_OFF ) {
		baseband_streaming_enable();
	}
}

transceiver_mode_t transceiver_mode(void) {
	return _transceiver_mode;
}

usb_request_status_t usb_vendor_request_set_transceiver_mode(
	usb_endpoint_t* const endpoint,
	const usb_transfer_stage_t stage
) {
	if( stage == USB_TRANSFER_STAGE_SETUP ) {
		switch( endpoint->setup.value ) {
		case TRANSCEIVER_MODE_OFF:
		case TRANSCEIVER_MODE_RX:
		case TRANSCEIVER_MODE_TX:
			set_transceiver_mode(endpoint->setup.value);
			usb_transfer_schedule_ack(endpoint->in);
			return USB_REQUEST_STATUS_OK;
		default:
			return USB_REQUEST_STATUS_STALL;
		}
	} else {
		return USB_REQUEST_STATUS_OK;
	}
}

static const usb_request_handler_fn vendor_request_handler[] = {
	NULL,
	usb_vendor_request_set_transceiver_mode,
    usb_vendor_request_write_adf4158,
    usb_vendor_request_read_adf4158,
    usb_vendor_request_set_gpio,
    usb_vendor_request_clear_gpio,
    usb_vendor_request_set_mcp,
    usb_vendor_request_set_clock,
    NULL,
    NULL,
	usb_vendor_request_erase_spiflash,
	usb_vendor_request_write_spiflash,
	usb_vendor_request_read_spiflash,
	NULL,
	usb_vendor_request_read_board_id,
	usb_vendor_request_read_version_string,
    NULL,
    NULL,
	usb_vendor_request_read_partid_serialno,
    NULL,
    NULL,
    NULL,
	NULL,
	NULL,
    NULL,
};

static const uint32_t vendor_request_handler_count =
	sizeof(vendor_request_handler) / sizeof(vendor_request_handler[0]);

usb_request_status_t usb_vendor_request(
	usb_endpoint_t* const endpoint,
	const usb_transfer_stage_t stage
) {
	usb_request_status_t status = USB_REQUEST_STATUS_STALL;

	if( endpoint->setup.request < vendor_request_handler_count ) {
		usb_request_handler_fn handler = vendor_request_handler[endpoint->setup.request];
		if( handler ) {
			status = handler(endpoint, stage);
		}
	}

	return status;
}

const usb_request_handlers_t usb_request_handlers = {
	.standard = usb_standard_request,
	.class = 0,
	.vendor = usb_vendor_request,
	.reserved = 0,
};

void usb_configuration_changed(
	usb_device_t* const device
) {
	/* Reset transceiver to idle state until other commands are received */
	set_transceiver_mode(TRANSCEIVER_MODE_OFF);
	if( device->configuration->number == 1 ) {
		// transceiver configuration
		cpu_clock_pll1_max_speed();
		//gpio_set(PORT_LED1_3, PIN_LED1);
	} else if( device->configuration->number == 2 ) {
		// CPLD update configuration
		cpu_clock_pll1_max_speed();
		usb_endpoint_init(&usb_endpoint_bulk_out);
		//start_cpld_update = true;
	} else {
		/* Configuration number equal 0 means usb bus reset. */
		cpu_clock_pll1_low_speed();
		//gpio_clear(PORT_LED1_3, PIN_LED1);
	}
}

void usb_set_descriptor_by_serial_number(void)
{
	iap_cmd_res_t iap_cmd_res;

	/* Read IAP Serial Number Identification */
	iap_cmd_res.cmd_param.command_code = IAP_CMD_READ_SERIAL_NO;
	iap_cmd_call(&iap_cmd_res);

	if (iap_cmd_res.status_res.status_ret == CMD_SUCCESS) {
		usb_descriptor_string_serial_number[0] = USB_DESCRIPTOR_STRING_SERIAL_BUF_LEN;
		usb_descriptor_string_serial_number[1] = USB_DESCRIPTOR_TYPE_STRING;

		/* 32 characters of serial number, convert to UTF-16LE */
		for (size_t i=0; i<USB_DESCRIPTOR_STRING_SERIAL_LEN; i++) {
			const uint_fast8_t nibble = (iap_cmd_res.status_res.iap_result[i >> 3] >> (28 - (i & 7) * 4)) & 0xf;
			const char c = (nibble > 9) ? ('a' + nibble - 10) : ('0' + nibble);
			usb_descriptor_string_serial_number[2 + i * 2] = c;
			usb_descriptor_string_serial_number[3 + i * 2] = 0x00;
		}
	} else {
		usb_descriptor_string_serial_number[0] = 2;
		usb_descriptor_string_serial_number[1] = USB_DESCRIPTOR_TYPE_STRING;
	}
}

int main(void) {
	pin_setup();

	cpu_clock_init();

	usb_set_descriptor_by_serial_number();

    gpio_clear(PORT_LED1_3, PIN_LED1);

	usb_set_configuration_changed_cb(usb_configuration_changed);

	usb_peripheral_reset();

	usb_device_init(0, &usb_device);

	usb_queue_init(&usb_endpoint_control_out_queue);
	usb_queue_init(&usb_endpoint_control_in_queue);
	usb_queue_init(&usb_endpoint_bulk_out_queue);
	usb_queue_init(&usb_endpoint_bulk_in_queue);

	usb_endpoint_init(&usb_endpoint_control_out);
	usb_endpoint_init(&usb_endpoint_control_in);

	nvic_set_priority(NVIC_USB0_IRQ, 255);
    vector_table.irq[NVIC_SGPIO_IRQ] = sgpio_isr_rx;

	usb_run(&usb_device);

	ssp1_init();

    sgpio_configure();

    mcp_init();

	while(true) {

    //gpio_set(PORT_LED1_3, PIN_LED1);
		// Set up IN transfer of buffer 0.
		if ( usb_bulk_buffer_offset >= 16384
		     && phase == 1
		     && transceiver_mode() != TRANSCEIVER_MODE_OFF) {
			usb_transfer_schedule_block(
				(transceiver_mode() == TRANSCEIVER_MODE_RX)
				? &usb_endpoint_bulk_in : &usb_endpoint_bulk_out,
				&usb_bulk_buffer[0x0000],
				0x4000,
				NULL, NULL
				);
			phase = 0;
		}
    //gpio_clear(PORT_LED1_3, PIN_LED1);

		// Set up IN transfer of buffer 1.
		if ( usb_bulk_buffer_offset < 16384
		     && phase == 0
		     && transceiver_mode() != TRANSCEIVER_MODE_OFF) {
			usb_transfer_schedule_block(
				(transceiver_mode() == TRANSCEIVER_MODE_RX)
				? &usb_endpoint_bulk_in : &usb_endpoint_bulk_out,
				&usb_bulk_buffer[0x4000],
				0x4000-32, // Last 32 bytes are unused
				NULL, NULL
			);
			phase = 1;
		}
	}

	return 0;
}

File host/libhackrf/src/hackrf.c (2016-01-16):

/*
Copyright (c) 2012, Jared Boone <jared@sharebrained.com>
Copyright (c) 2013, Benjamin Vernoux <titanmkd@gmail.com>
Copyright (c) 2013, Michael Ossmann <mike@ossmann.com>

All rights reserved.

Redistribution and use in source and binary forms, with or without modification, are permitted provided that the following conditions are met:

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
THIS SOFTWARE IS PROVIDED BY THE COPYRIGHT HOLDERS AND CONTRIBUTORS "AS IS" AND ANY EXPRESS OR IMPLIED WARRANTIES, INCLUDING, BUT NOT LIMITED TO, 
THE IMPLIED WARRANTIES OF MERCHANTABILITY AND FITNESS FOR A PARTICULAR PURPOSE ARE DISCLAIMED.
IN NO EVENT SHALL THE COPYRIGHT HOLDER OR CONTRIBUTORS BE LIABLE FOR ANY DIRECT, INDIRECT, INCIDENTAL, SPECIAL, EXEMPLARY, OR CONSEQUENTIAL DAMAGES
(INCLUDING, BUT NOT LIMITED TO, PROCUREMENT OF SUBSTITUTE GOODS OR SERVICES; LOSS OF USE, DATA, OR PROFITS; OR BUSINESS INTERRUPTION)
HOWEVER CAUSED AND ON ANY THEORY OF LIABILITY, WHETHER IN CONTRACT, STRICT LIABILITY, OR TORT (INCLUDING NEGLIGENCE OR OTHERWISE)
ARISING IN ANY WAY OUT OF THE USE OF THIS SOFTWARE, EVEN IF ADVISED OF THE POSSIBILITY OF SUCH DAMAGE.
*/

#include "hackrf.h"

#include <stdlib.h>

#include <libusb.h>
#include <string.h>
#include <pthread.h>
#include <math.h>

#ifndef bool
typedef int bool;
#define true 1
#define false 0
#endif

//ADF4158 reference oscillator frequency
#define FPD_FREQ 30000000

#ifdef HACKRF_BIG_ENDIAN
#define TO_LE(x) __builtin_bswap32(x)
#define TO_LE64(x) __builtin_bswap64(x)
#else
#define TO_LE(x) x
#define TO_LE64(x) x
#endif

#define GPIO_ADF (1 << 0)
#define GPIO_ADC (1 << 1)
#define GPIO_PA  (1 << 2)
#define GPIO_MIXER (1 << 3)
#define GPIO_LED (1 << 4)

// TODO: Factor this into a shared #include so that firmware can use
// the same values.
typedef enum {
	HACKRF_VENDOR_REQUEST_SET_TRANSCEIVER_MODE = 1,
	HACKRF_VENDOR_REQUEST_ADF4158_WRITE = 2,
	HACKRF_VENDOR_REQUEST_ADF4158READ = 3,
	HACKRF_VENDOR_REQUEST_SET_GPIO = 4,
	HACKRF_VENDOR_REQUEST_CLEAR_GPIO = 5,
	HACKRF_VENDOR_REQUEST_SET_MCP = 6,
	HACKRF_VENDOR_REQUEST_SET_CLOCK = 7,
	HACKRF_VENDOR_REQUEST_SPIFLASH_ERASE = 10,
	HACKRF_VENDOR_REQUEST_SPIFLASH_WRITE = 11,
	HACKRF_VENDOR_REQUEST_SPIFLASH_READ = 12,
	HACKRF_VENDOR_REQUEST_BOARD_ID_READ = 14,
	HACKRF_VENDOR_REQUEST_VERSION_STRING_READ = 15,
	HACKRF_VENDOR_REQUEST_BOARD_PARTID_SERIALNO_READ = 18,
} hackrf_vendor_request;

typedef enum {
	USB_CONFIG_STANDARD = 0x1,
	USB_CONFIG_CPLD_UPDATE  = 0x2,
} hackrf_usb_configurations;

typedef enum {
	HACKRF_TRANSCEIVER_MODE_OFF = 0,
	HACKRF_TRANSCEIVER_MODE_RECEIVE = 1,
	HACKRF_TRANSCEIVER_MODE_TRANSMIT = 2,
} hackrf_transceiver_mode;

struct hackrf_device {
	libusb_device_handle* usb_device;
	struct libusb_transfer** transfers;
	hackrf_sample_block_cb_fn callback;
	volatile bool transfer_thread_started; /* volatile shared between threads (read only) */
	pthread_t transfer_thread;
	uint32_t transfer_count;
	uint32_t buffer_size;
	volatile bool streaming; /* volatile shared between threads (read only) */
	void* rx_ctx;
	void* tx_ctx;
};

typedef struct {
	uint32_t bandwidth_hz;
} max2837_ft_t;

static const max2837_ft_t max2837_ft[] = {
	{ 1750000  },
	{ 2500000  },
	{ 3500000  },
	{ 5000000  },
	{ 5500000  },
	{ 6000000  },
	{ 7000000  },
	{ 8000000  },
	{ 9000000  },
	{ 10000000 },
	{ 12000000 },
	{ 14000000 },
	{ 15000000 },
	{ 20000000 },
	{ 24000000 },
	{ 28000000 },
	{ 0        }
};

typedef struct {
    char *name;
    int reg;
    int bit;
    int len;
} adf_reg;

const static adf_reg adf4158_regs[] = {
    { "frac_msb", 0, 3, 12 },
    { "n", 0, 15, 12 },
    { "muxout", 0, 27, 4 },
    { "ramp_on", 0, 31, 1 },
    { "frac_lsb", 1, 15, 13 },
    { "reserved1", 1, 3, 12 },
    { "reserved0", 1, 28, 4 },
    { "r_counter", 2, 15, 5 },
    { "csr_en", 2, 28, 1 },
    { "rdiv2", 2, 21, 1 },
    { "prescaler", 2, 22, 1 },
    { "reference_doubler", 2, 20, 1 },
    { "cp_current", 2, 24, 4 },
    { "clk1_divider", 2, 3, 12 },
    { "reserved3", 2, 23, 1 },
    { "reserved2", 2, 29, 3 },
    { "power_down", 3, 5, 1 },
    { "psk_enable", 3, 9, 1 },
    { "fsk_enable", 3, 8, 1 },
    { "sd_reset", 3, 14, 1 },
    { "counter_reset", 3, 3, 1 },
    { "reserved5", 3, 12, 2 },
    { "reserved4", 3, 16, 16 },
    { "ramp_mode", 3, 10, 2 },
    { "n_sel", 3, 15, 1 },
    { "cp_3state", 3, 4, 1 },
    { "lpd", 3, 7, 1 },
    { "pd_polarity", 3, 6, 1 },
    { "neg_bleed_current", 4, 23, 2 },
    { "clk_div_mode", 4, 19, 2 },
    { "clk2_divider", 4, 7, 12 },
    { "sd_mod_mode", 4, 26, 5 },
    { "reserved7", 4, 3, 4 },
    { "reserved6", 4, 25, 1 },
    { "lf_sel", 4, 31, 1 },
    { "readback_to_muxout", 4, 21, 2 },
    { "fsk_ramp_en", 5, 25, 1 },
    { "tx_ramp_clk", 5, 29, 1 },
    { "dev_offset", 5, 19, 4 },
    { "par_ramp", 5, 28, 1 },
    { "reserved8", 5, 30, 2 },
    { "dev_sel", 5, 23, 1 },
    { "interrupt", 5, 26, 2 },
    { "ramp2_en", 5, 24, 1 },
    { "deviation", 5, 3, 16 },
    { "step", 6, 3, 20 },
    { "reserved9", 6, 24, 8 },
    { "step_sel", 6, 23, 1 },
    { "reserved10", 7, 19, 13 },
    { "ramp_del", 7, 17, 1 },
    { "ramp_del_fl", 7, 18, 1 },
    { "del_start_en", 7, 15, 1 },
    { "delay_start_divider", 7, 3, 12 },
    { "del_clk_sel", 7, 16, 1 },
    { "", 0, 0, 0}
};

static int hackrf_adf4158_reg_to_device(hackrf_device* device, unsigned int reg);

static uint32_t adf4158[8] = {0};

volatile bool do_exit = false;

static const uint16_t hackrf_usb_vid = 0x1d50;
static const uint16_t hackrf_jawbreaker_usb_pid = 0x604b;
static const uint16_t hackrf_one_usb_pid = 0x6099;
static const uint16_t rad1o_usb_pid = 0xcc15;

static libusb_context* g_libusb_context = NULL;

static void request_exit(void)
{
	do_exit = true;
}

static int cancel_transfers(hackrf_device* device)
{
	uint32_t transfer_index;

	if( device->transfers != NULL )
	{
		for(transfer_index=0; transfer_index<device->transfer_count; transfer_index++)
		{
			if( device->transfers[transfer_index] != NULL )
			{
				libusb_cancel_transfer(device->transfers[transfer_index]);
			}
		}
		return HACKRF_SUCCESS;
	} else {
		return HACKRF_ERROR_OTHER;
	}
}

static int free_transfers(hackrf_device* device)
{
	uint32_t transfer_index;

	if( device->transfers != NULL )
	{
		// libusb_close() should free all transfers referenced from this array.
		for(transfer_index=0; transfer_index<device->transfer_count; transfer_index++)
		{
			if( device->transfers[transfer_index] != NULL )
			{
				libusb_free_transfer(device->transfers[transfer_index]);
				device->transfers[transfer_index] = NULL;
			}
		}
		free(device->transfers);
		device->transfers = NULL;
	}
	return HACKRF_SUCCESS;
}
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

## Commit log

2015-08-29 Use all 10bits from ADC
    Add some forgotten files.
2015-08-29 Add filtering + decimation tool
2015-08-29 Fix filtering script
2015-08-30 Send sync words
    Needs jump wire from SSP1_MISO to P5.
    Uses the ramp complete signal from ADF4158 to synchronize the ramps.
2015-09-06 Update processing programs
    Multithreaded file writing in transfer program
    Add header to saved files
    Enable pullup in ramp complete input pin
2015-10-13 Add hardware design files
    [fmcw2.kicad_pcb, fmcw2.sch, fmcw2_mcu.kicad_pcb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]
2015-10-13 Add PDF of schematic
2015-11-09 Rescue schematic symbols to a new library
    Schematic used old symbols and without cached library files
    uses instead the new symbols that have different pin pitch.
    [fmcw2.sch, fmcw2_mcu.sch]
2015-11-09 Add jump wire transistor
    Scretches the ramp complete pulse from ADF4158.
    Internal pull-up resistor of the microcontroller pin is used
    to pull-up the transistor drain.
    [fmcw2_mcu.kicad_pcb, fmcw2_mcu.sch]
2016-01-16 Change inductors to better shielded ones
    Previous inductors weren't too well shielded and radiated a lot.
    Footprint is unchanged.
    R27 is also changed to 1k from 10k to increase PSRR.
    [fmcw2_mcu.sch]
2016-01-16 Increase PLL loop bandwidth
    Faster frequency settling
    [fmcw2.kicad_pcb, fmcw2.sch]
2016-03-09 Improve SMA connector footprint
    Better matching than the previous one.
    [fmcw2.kicad_pcb]
2016-07-13 Add libopencm3 folder
    [adc.csv, atimer.csv, ccu.csv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]
2016-12-22 Disable baseband filter compensation code

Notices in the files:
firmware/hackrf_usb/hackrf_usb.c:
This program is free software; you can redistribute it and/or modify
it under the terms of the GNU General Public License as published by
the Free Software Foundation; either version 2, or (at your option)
